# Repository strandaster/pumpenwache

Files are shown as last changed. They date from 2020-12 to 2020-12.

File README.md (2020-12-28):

# Pumpenwache
Ziel des Projektes war, die Pausenzeiten die Pumpe der Drainage, die um unser Haus liegt, zu überwachen. Anhand der Pausenzeiten kann man abschätzen, ob viel oder wenig Wasser am Haus steht. Außerdem ist eine Funktionskontrolle gegeben. Um die Umgebungswerte des Kellerraumes zu überwachen, wurde noch ein Temperatur- und Feuchtigkeitssensor verbaut.

## Technische Umsetzung
### benötigte Bauteile
* Stromsensor ACS712 (passend zur erwarteten Stromstärke)
* ESP8266 (in diesem Projekt wurde ein Wemos D1 mini verwendet)
* BME280 (für die Messung der Umgebungswerte)
* Kleinteile um die Schaltung aufzubauen

### Schaltplan
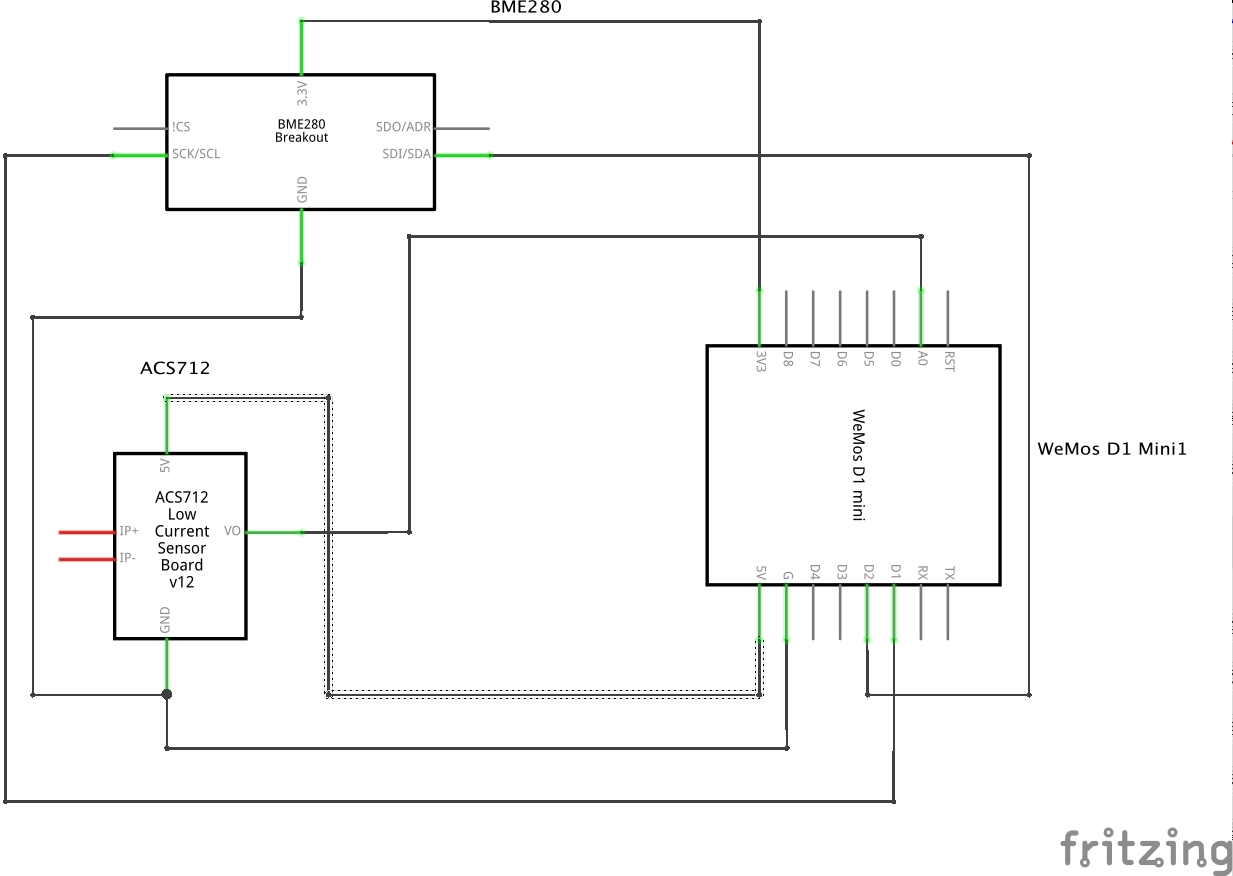
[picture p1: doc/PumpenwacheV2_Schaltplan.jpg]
Schaltplan


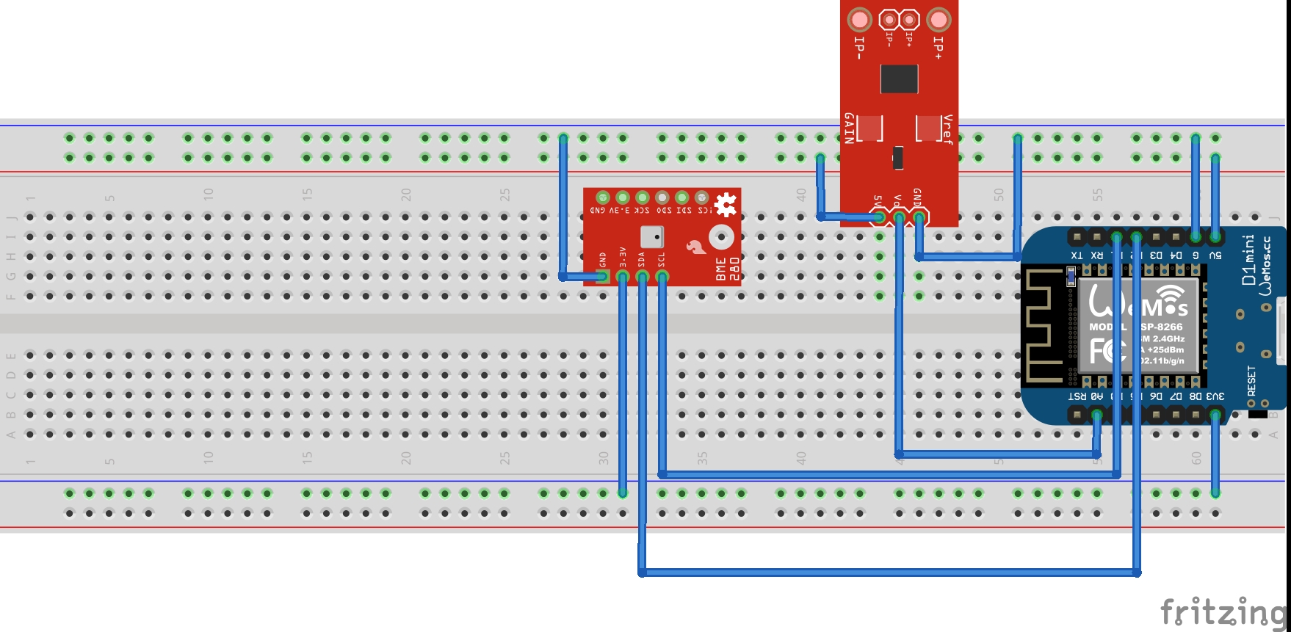
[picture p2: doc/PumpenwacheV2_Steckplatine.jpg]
Steckbrett-Ansicht


### Software
**verwendete Bibliotheken:**
  * ACS712-Arduino (<https://github.com/strandaster/ACS712-arduino.git>)
  * BME280 (ID:901) (<https://github.com/finitespace/BME280.git>)
  * Telnetspy (<https://github.com/strandaster/telnetspy.git>)

Die Bibliotheken ACS712-Arduino und TelnetSpy wurden angepasst, damit sie mit der aktuellen Arduino Version funktionieren.

**Ablaufbeschreibung:**
Die Umgebungswerte wie Temperatur und Luftfeuchtigkeit werden alle 15 Minuten abgefragt und durch den Aufruf eines PHP-Skriptes auf eine entfernte mySQL-Datenbank gespeichert.
Alle 15 Sekunden wird geprüft, ob ein Stromfluss am Sensor ACS712 detektiert werden kann. Übersteigt der Wert einen Schwellwert, wird die Pumpe als aktiv gekennzeichnet. Fällt der Wert wieder (die Pumpe hat den Pumpensumpf leergepumpt), wird ein PHP-Skript aufgerufen, um die letzte Pumpenaktivität zu melden.

Für Debug-Zwecke kann sich mittels Telnet (Port 23) mit dem Mikrocontroller verbunden werden. 

Um den Quellcode zu aktualisieren "drahtlos" zu aktualisieren, wurde ArduinoOTA implementiert. 

### Auswertung
In der mySQL Datenbank werden folgende Objekte benötigt:
* Tabelle **_dataV2_**
  * **_Time_** timestamp NOT NULL DEFAULT CURRENT_TIMESTAMP
  * **_Amps_** float NOT NULL
* Trigger auf _dataV2_ um einen Eintrag in der Tabelle _diff_ anzulegen
* Tabelle **_diff_**
  * **_Time_** timestamp NOT NULL DEFAULT CURRENT_TIMESTAMP
  * **_diff_** int(11) DEFAULT NULL
* Tabelle **_Umwelt_**
  * **_Time_** timestamp NOT NULL DEFAULT CURRENT_TIMESTAMP
  * **_Temperatur_** float DEFAULT NULL
  * **_Feuchtigkeit_** float DEFAULT NULL
  * **_Luftdruck_** float DEFAULT NULL

Für die grafische Auswertung wird [Google Charts](https://developers.google.com/chart) genutzt. 
Die Pumpenaktivität wird mittels _pumpe.php_ und die Umgebungswerte mittels _umwelt.php_ visualisiert.

Für die Nutzung der Werte im [Home Assistant](https://www.home-assistant.io) übergibt das PHP Skript _umweltsensor.php_ die Werte als JSON Array.

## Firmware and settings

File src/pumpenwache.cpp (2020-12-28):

#include <Arduino.h>
#include <ACS712.h>
#include <ESP8266WiFi.h>
#include <Wire.h>
#include <SPI.h>
#include <BME280I2C.h>
#include <ArduinoOTA.h>
#include <TelnetSpy.h>
#include <ESP8266HTTPClient.h>
#include <pumpenwache.h>


TelnetSpy SerialAndTelnet;
#define SERIAL SerialAndTelnet


boolean pumpeAktiv = false;

// variables for timestamps
unsigned long lastEnvTimeStamp=0;
unsigned long lastACTimeStamp=0;
unsigned long lastCalTimeStamp=0;
unsigned long time_now;

// variables for environment
float globalTemp=0;
float globalPressure=0;
float globalHumidity=0;
float currentAC = 0;

int calValue=0;

ACS712 sensor(ACS712_20A, ACS712PIN);

// BME280 config
 BME280I2C::Settings settings(
   BME280::OSR_X1,
   BME280::OSR_X16,
   BME280::OSR_X1,
   BME280::Mode_Forced,
   BME280::StandbyTime_1000ms,
   BME280::Filter_Off,
   BME280::SpiEnable_False,
   BME280I2C::I2CAddr_0x76 // I2C address. I2C specific.
);
BME280I2C bme(settings); 

void setup() {
  Serial.begin(115200);

  WiFi.mode(WIFI_STA);
  WiFi.setSleepMode(WIFI_NONE_SLEEP);
  WiFi.hostname(HOSTNAME);
  WiFi.persistent(false);
  WiFi.begin(SSID, WLAN_KEY);
  while (WiFi.status() != WL_CONNECTED) {
    delay(500);
    Serial.print(".");
  };
  Serial.println("");
  Serial.println("WiFi connected");
  Serial.println("IP address: ");
  Serial.println(WiFi.localIP());

  initBME();
  initArduinoOTA();
  SERIAL.begin(115200);

  sensor.setVoltageReference(VOLTAGE_REFERENCE_VALUE);

  calValue = sensor.calibrate();
  Serial.print("Calibration value: ");
  Serial.println(calValue);

  sensor.setZeroPoint(ACS_CALIBRATION_VALUE);

  //set value to negative to get a current value during start up
  lastEnvTimeStamp = millis() - TIMER_INTERVAL_UPDATE_ENV;
}

void loop() {
 time_now = millis();

if (checkTimer(time_now, lastEnvTimeStamp, TIMER_INTERVAL_UPDATE_ENV)) {
  // it is time for getting environment values like temperature
  readEnvValues();
  lastEnvTimeStamp=time_now;

  sendEnvToDB();
} 

if (checkTimer(time_now, lastACTimeStamp, TIMER_INTERVAL_AC)) {
  // check AC usage
  SERIAL.printf("Cal Value: %i \n", calValue);
  currentAC = readACValue();
  SERIAL.printf("get AC current: %f \n",currentAC);
  SERIAL.printf("current W: %f \n", currentAC*230);

  float currentVoltage = sensor.getVoltage();
  SERIAL.printf("current Voltage: %f \n", currentVoltage);

  float currentDC = sensor.getCurrentDC();
  SERIAL.printf("current DC: %f \n", currentDC);

  // compare to defined min value
  if (currentAC >= CURRENT_MIN_VALUE && !pumpeAktiv) {
    pumpeAktiv = true;
    sendAmpsToDB();
  }
  else if (currentAC <= CURRENT_MIN_VALUE && pumpeAktiv) {
    pumpeAktiv = false;
  }

  lastACTimeStamp = time_now;
}

if (checkTimer(time_now, lastCalTimeStamp, TIMER_INTERVAL_CALIBRATE) && !pumpeAktiv) {
  // calibrate the sensor after defined time. The calibrated value will only saved but nut used.
  lastCalTimeStamp=time_now;
  calValue = sensor.calibrate();
} 

 ArduinoOTA.handle();
 SERIAL.handle();
 yield();

}

/* 
 * retrieves environment values (temperature, humidity and pressure)
 */
void readEnvValues() {
  bme.read(globalPressure, globalTemp, globalHumidity,tempUnit, presUnit);

  SERIAL.printf("Humidity: %f \n", globalHumidity);
  SERIAL.printf("Temperatur: %f \n", globalTemp);
  SERIAL.printf("Pressure: %f \n", globalPressure);
}

/*
 * execute a check if new data should be retrieved
 */
boolean checkTimer(unsigned long currentTimeStamp, unsigned long lastTimeStamp, unsigned long timer_interval) {
  if (currentTimeStamp - lastTimeStamp < timer_interval) {
    return false;
  }
  else {
    return true;
  }
}

/*
 * init the BME sensor 
 */
void initBME() {
  Wire.begin();
  while(!bme.begin()) 
  {
    SERIAL.println("Could not find BME280 sensor!");
    delay(1000);
  } 
  settings.presOSR = BME280::OSR_X1;
  settings.humOSR = BME280::OSR_X16;

  bme.setSettings(settings);

}

/* 
 * init Over the air update 
 */
void initArduinoOTA() {
  ArduinoOTA.setHostname(HOSTNAME);

  ArduinoOTA.onStart([]() {
    String type;
    if (ArduinoOTA.getCommand() == U_FLASH) {
      type = "sketch";
    } else { // U_SPIFFS
      type = "filesystem";
    }

    // NOTE: if updating SPIFFS this would be the place to unmount SPIFFS using SPIFFS.end()
    Serial.println("Start updating " + type);
  });
  ArduinoOTA.onEnd([]() {
    Serial.println("\nEnd");
  });
  ArduinoOTA.onProgress([](unsigned int progress, unsigned int total) {
    Serial.printf("Progress: %u%%\r", (progress / (total / 100)));
  });
  ArduinoOTA.onError([](ota_error_t error) {
    Serial.printf("Error[%u]: ", error);
    if (error == OTA_AUTH_ERROR) {
      Serial.println("Auth Failed");
    } else if (error == OTA_BEGIN_ERROR) {
      Serial.println("Begin Failed");
    } else if (error == OTA_CONNECT_ERROR) {
      Serial.println("Connect Failed");
    } else if (error == OTA_RECEIVE_ERROR) {
      Serial.println("Receive Failed");
    } else if (error == OTA_END_ERROR) {
      Serial.println("End Failed");
    }
  });
ArduinoOTA.begin();
}

/*
 * read AC value 
 */
float readACValue() {
  float current = sensor.getCurrentAC();
  if (current < 0.2f) {
    return 0.0f;
  }
  else {
    return current;
  }
}

/*
 * collect values and send the environment data to database
 */
void sendEnvToDB() {
    String requestData;
    requestData = requestData + "&temperatur=" + globalTemp + "&feuchtigkeit=" + globalHumidity
                          + "&luftdruck=" + globalPressure + ""; 
    sendHttpRequest(DB_PHP_INSERT_ENV_SCRIPT, requestData);
}

/*
 * collect Amps value and send it to database
 */
void sendAmpsToDB() {
  String requestData = "&Amps=";
  requestData = requestData + currentAC;
  sendHttpRequest(DB_PHP_INSERT_ACTIVITY_SCRIPT,requestData);
  }

/*
 * generates HTTP request and call the PHP script on webspace
 */
void sendHttpRequest(char* url, String requestData ) {
  HTTPClient http;
  http.begin(url);

  // Specify content-type header
  http.addHeader("Content-Type", "application/x-www-form-urlencoded");

  // Prepare your HTTP POST request data
  String httpRequestData = "api_key=" + DB_PHP_API_KEY + requestData;

  SERIAL.print("httpRequestData: ");
  SERIAL.println(httpRequestData);

  // Send HTTP POST request
  int httpResponseCode = http.POST(httpRequestData);

  // If you need an HTTP request with a content type: text/plain
  http.addHeader("Content-Type", "text/plain");

  if (httpResponseCode > 0)
  {
    SERIAL.print("HTTP Response code: ");
    SERIAL.println(httpResponseCode);
    SERIAL.println(http.getString());
  }
  else
  {
    SERIAL.print("Error code: ");
    SERIAL.println(httpResponseCode);
  }
  // Free resources
  http.end();
}

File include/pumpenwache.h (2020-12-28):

#define SSID  "<YOUR_WLAN_SSID>"
#define WLAN_KEY "<YOUR_WLAN_KEY>"

#define HOSTNAME "<YOUR_HOSTNAME>"

#ifndef min
#define min(a,b) ((a)<(b)?(a):(b))
#endif
#ifndef max
#define max(a,b) ((a)>(b)?(a):(b))
#endif

void readEnvValues();
void initBME();
void initArduinoOTA();
void initRemoteDebug();
float readACValue();
void sendEnvToDB();
void sendAmpsToDB();
void sendHttpRequest(char* url, String requestData );

boolean checkTimer(unsigned long, unsigned long, unsigned long);

BME280::TempUnit tempUnit(BME280::TempUnit_Celsius);  
BME280::PresUnit presUnit(BME280::PresUnit_hPa);

#define ACS712PIN A0
#define ACS_CALIBRATION_VALUE 785 //muss noch mittels calibrate ermittelt werden und dann per setZero gesetzt werden.
#define VOLTAGE_REFERENCE_VALUE 4.4

#define TIMER_INTERVAL_UPDATE_ENV  900000 //15 min
#define TIMER_INTERVAL_AC 15000 // 15s
#define TIMER_INTERVAL_CALIBRATE 3600000 //60 min 
#define CURRENT_MIN_VALUE 1.8

#define DB_PHP_INSERT_ENV_SCRIPT "http://<YOUR_WEBSPACE>/pumpenwache-post-data.php"
#define DB_PHP_INSERT_ACTIVITY_SCRIPT "http://<YOUR_WEBSPACE>/pumpenwache-post-activity.php"
String DB_PHP_API_KEY = "<YOUR_API_KEY>";
